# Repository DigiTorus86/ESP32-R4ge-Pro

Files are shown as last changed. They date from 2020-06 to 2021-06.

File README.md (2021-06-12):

# ESP32-R4ge-Pro
<p>
Software and resources for the ESP32 R4ge Pro custom badge. See documents folder for schematic.  
</p>

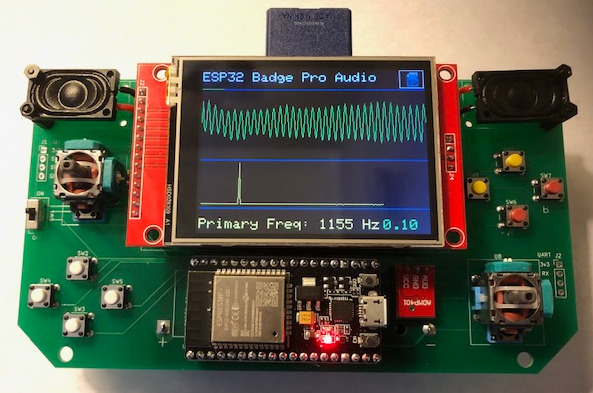
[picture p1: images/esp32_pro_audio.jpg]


<h3>Key Components/Requirements</h3>
<p>
- <a href="https://www.pcbway.com/project/shareproject/ESP32_R4ge_Pro.html">Custom PCB</a><br>
- ESP32 DevKitC w/38 pins (other ESP32 boards can be used with minimal PIN changes)<br>
- ILI9341 320x240 TFT with touch and SD card slot<br>
- 2 Analog joysticks<br>
- PCM5102a I2S DAC w/headphone jack<br>
- PAM8403 amplifier and 8 Ohm/1W speakers and/or powered external speakers w/3.5mm jack<br>
- Microphone (i.e. ADMP401)<br>
- Some sketches have additional hardware requirements (components attached to I2C or Serial pins, or SD card)<br>
- See BOM file in the documents folder for full list of components.<br>
- STL file for printing a simple case also included in the documents folder.<br>
</p>
<h3>App Descriptions</h3>
<p>
- Audio:   Allows for WAV recording, play back, serialization, and frequency analysis.  Requires SD card for some functions.<br>
- BLE Controller:   Allows you to use the joysticks and buttons of the ESP32 R4ge Pro to control another ESP32/Bluetooth device operating in the central role, such as a robot tank.<br> 
- BLE Tank Commander:  Receives BLE control signals from the Controller sketch and feeds them to an H-bridge control board for driving a robot tank or other motorized chassis.  Runs on a generic ESP32 board.<br>   
- Drummer: A 4-channel sequencer using percussion samples.<br>
- Gravitack:  Classic space shooter. (Port from original ESP32 Conference Badge) <br>
- Prong:   A simple pong-type game for 1 or 2 players.<br>
- Synth:   A graphical 4-operator/4-voice FM synth, playable via on-screen keyboard + stylus, 8 step sequencer, or MIDI input on the RX2 pin. 
- Test1:   Used to verify the operation of the board components and do any calibration (microphone/joysticks).<br> 
- Time and Weather:  Clock and weather station. (Port from original ESP32 Conference Badge)<br>
- Tombstone:  Port of the classic TI game.<br>    
- Web Radio:  Internet radio station selector and player.<br>
</p>
<p>
Check for additional info on my blog at https://twobittinker.com<br> 
</p>

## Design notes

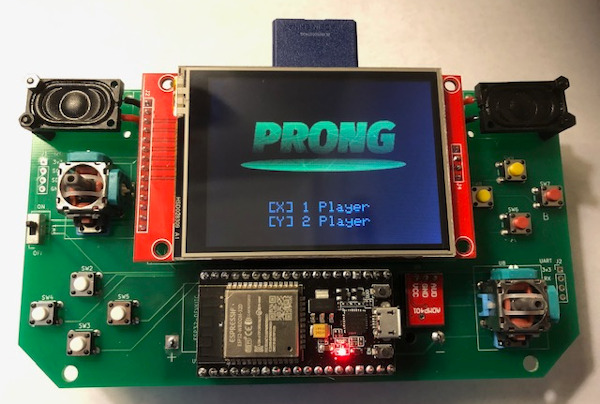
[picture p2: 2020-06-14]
images/esp32_prong.jpg

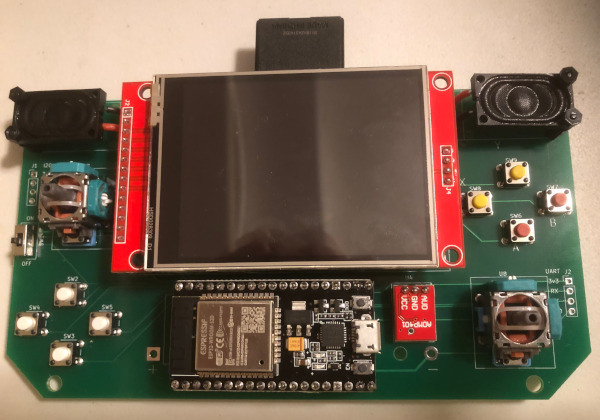
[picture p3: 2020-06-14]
images/ESP32_R4ge_Pro.jpg

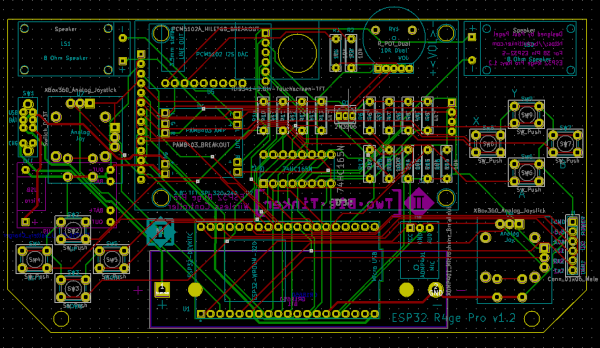
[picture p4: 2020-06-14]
images/ESP32-R4ge-Pro-layoutsm.png

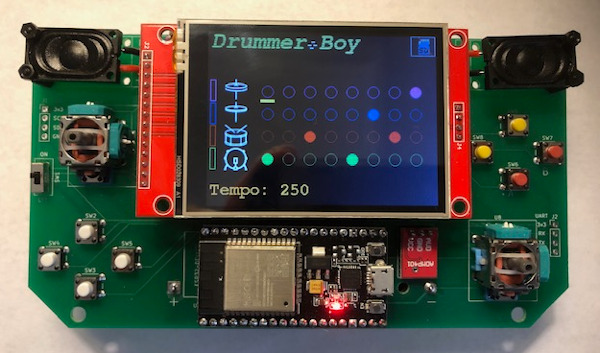
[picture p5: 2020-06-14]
images/esp32_drummer_boy.jpg

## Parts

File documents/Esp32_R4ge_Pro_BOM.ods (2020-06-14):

Component | Description | References | Value | Footprint | Quantity Per PCB | Datasheet | Order URL | Price EA | Total Price
1 | CR18650 Li-Ion rechargeable battery | BT1 | CR18650 | BatteryHolder_MPD_BH-18650-PC2 | 1 | ~ | https://www.amazon.com/gp/product/B07D1FRL54 | 1.25 | 1.25
2 | Generic 2.54mm male break-away connector, single row, 01x06 | J1 | Conn_01x06_Male | PinHeader_1x06_P2.54mm_Vertical | 1 | ~ | https://www.amazon.com/MCIGICM-Header-2-45mm-Arduino-Connector/dp/B07PKKY8BX | 0.5 | 0.5
3 | 8 Ohm 1W Speaker | LS1 LS2 | Speaker | Speaker_Visaton_K14.25_8_ohm | 2 | https://www.mouser.com/datasheet/2/700/k14_25_8-1285071.pdf | https://www.mouser.com/ProductDetail/243-K14.25-8OHM | 4 | 8
4 | -0.2A Ic, -40V Vce, Small Signal PNP Transistor, TO-92 | Q1 | 2N3906 | TO-92_Inline | 1 | https://www.fairchildsemi.com/datasheets/2N/2N3906.pdf | https://www.amazon.com/McIgIcM-Transistor-Bipolar-Transistors-Through/dp/B06XR8399W | 0.03 | 0.03
5 | Resistor | R18 | 100R | R_Axial_DIN0207_L6.3mm_D2.5mm_P7.62mm_Horizontal | 1 | ~ | https://www.amazon.com/EDGELEC-Resistor-Tolerance-Multiple-Resistance/dp/B07QKDSCSM | 0.05 | 0.05
6 | Resistor | R1 R2 R14 R15 R16 | 10K | R_Axial_DIN0207_L6.3mm_D2.5mm_P7.62mm_Horizontal | 5 | ~ | https://www.amazon.com/EDGELEC-Resistor-Tolerance-Resistance-Optional/dp/B07HDGX5LM | 0.05 | 0.25
7 | Resistor | R17 | 1K | R_Axial_DIN0207_L6.3mm_D2.5mm_P7.62mm_Horizontal | 1 | ~ | https://www.amazon.com/EDGELEC-Resistor-Tolerance-Resistance-Optional/dp/B07HDDWFDD | 0.05 | 0.05
8 | Resistor | R6 R7 R8 R9 R10 R11 R12 R13 | 4K7 | R_Axial_DIN0207_L6.3mm_D2.5mm_P7.62mm_Horizontal | 8 | ~ | https://www.amazon.com/EDGELEC-Resistor-Tolerance-Resistance-Optional/dp/B07HDFHPP3 | 0.05 | 0.4
9 | 10k dual channel potentiometer | RV1 | R_POT_Dual | Potentiometer_10K_Dual_Uxcell | 1 | ~ | https://www.amazon.com/gp/product/B00O9Y6Z70 | 1 | 1
10 | Push button switch, generic, two pins | SW2 SW3 SW4 SW5 SW6 SW7 SW8 SW9 | SW_Push | SW_PUSH_6mm | 8 | ~ | https://www.amazon.com/gp/product/B07C7211PJ | 0.06 | 0.48
11 | Dual Pole 3 Position power switch | SW1 | Switch_DP3T | Switch_DP3T_CK_OS203011MS1QP1 | 1 |  | https://www.mouser.com/ProductDetail/611-OS203011MV9QN1 | 0.5 | 0.5
12 | 74HC165N Shift Register, DIP-16 | U3 | 74HC165N | DIP254P762X420-16 | 1 | 380635 | https://www.amazon.com/Brands-74HC165-Semiconductors-Parallel-Register/dp/B06WRRLPSW | 0.8 | 0.8
13 | ADMP401 MEMS microphone breakout | U4 | ADMP401_Microphone_Breakout | ADMP401_Microphone_Breakout | 1 |  | https://www.amazon.com/ADMP401-Microphone-Breakout-Universal-1-3cm1cm/dp/B07VJXP2NN | 4.3 | 4.3
14 | ESP32 WROOM-32D DevkitC/nodeMCU-S w/38 pins | U1 | ESP32-DEVKITC | MODULE_ESP32-DEVKITC | 1 | None | https://www.amazon.com/HiLetgo-ESP-WROOM-32-Development-Microcontroller-Integrated/dp/B0718T232Z | 10.99 | 10.99
15 | 2.8” SPI Touchscreen TFT w/SD card, ILI9341 | U2 | ILI9341-2.8in-Touchscreen-TFT | ILI9341_2.8_TFT_TOUCH_SD_SPI | 1 | http://pan.baidu.com/s/11Y990 | https://www.amazon.com/gp/product/B073R7BH1B | 13.99 | 13.99
16 | PAM8403 stereo amplifier breakout | U6 | PAM8403_BREAKOUT | PAM8403_Breakout_HW104 | 1 |  | https://www.amazon.com/gp/product/B00LODGV64 | 1.08 | 1.08
17 | PCM5102 I2S stereo DAC breakout | U5 | PCM5102A_HILETGO_BREAKOUT | PCM5102A_Hiletgo_Breakout | 1 |  | https://www.amazon.com/HiLetgo-Lossless-Digital-Converter-Raspberry/dp/B07Q9K5MT8 | 8 | 8
18 | TP4056 5v Li-Ion battery charger w/diode protection | U9 | TP4056_5V_Li_Battery_Charger | TP4056_Li_Battery_Charger_Breakout | 1 |  | https://www.amazon.com/gp/product/B071RG4YWM | 1 | 1
19 | XBox360 analog joystick | U7 U8 | XBox360_Analog_Joystick | XBox360_Analog_Joystick | 2 |  | https://www.amazon.com/Replacement-Analog-Controller-Joystick-Playstation/dp/B07SW7SRLH | 1.5 | 3
20 | Generic 2.54mm female header connectors | U1, U2 | for ESP32 and TFT |  | 2 |  | https://www.amazon.com/Haobase-2-54mm-Straight-Single-Headers/dp/B01DLX6RSQ | 0.56 | 1.12
 | 16pin IC socket | U3 | for 74HC165N |  | 1 |  | https://www.amazon.com/Uxcell-a11090300ux0244-2-54mm-Socket-Adaptors/dp/B0079SM1LW | 0.35 | 0.35
 |  |  |  |  |  |  |  | TOTAL | 57.14
Component Groups: | 19
Component Count: | 39
Fitted Components: | 39
Number of PCBs: | 1
Total components: | 39
Schematic Version: | 3
Schematic Date: | 2020-04-05
PCB Variant: | [u'default']
BoM Date: | Wed 08 Apr 2020 05:32:06 PM EDT
Schematic Source: | /home/digitorus/KiCad/ESP32_R4ge_Pro/Esp32Badge-v1/Esp32Badge-v1.sch
KiCad Version: | Eeschema 5.1.5-52549c5~86~ubuntu19.10.1

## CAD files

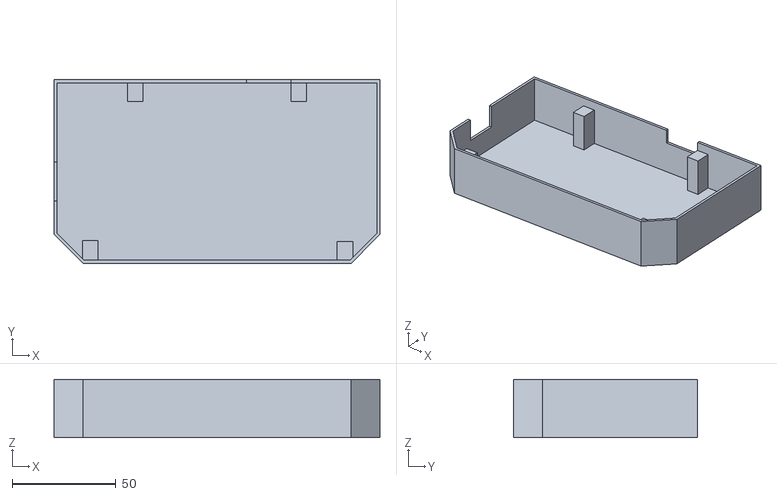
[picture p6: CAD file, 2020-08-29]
documents/Rage_Pro_Case3.stl
156.8 x 88.4 x 28.0

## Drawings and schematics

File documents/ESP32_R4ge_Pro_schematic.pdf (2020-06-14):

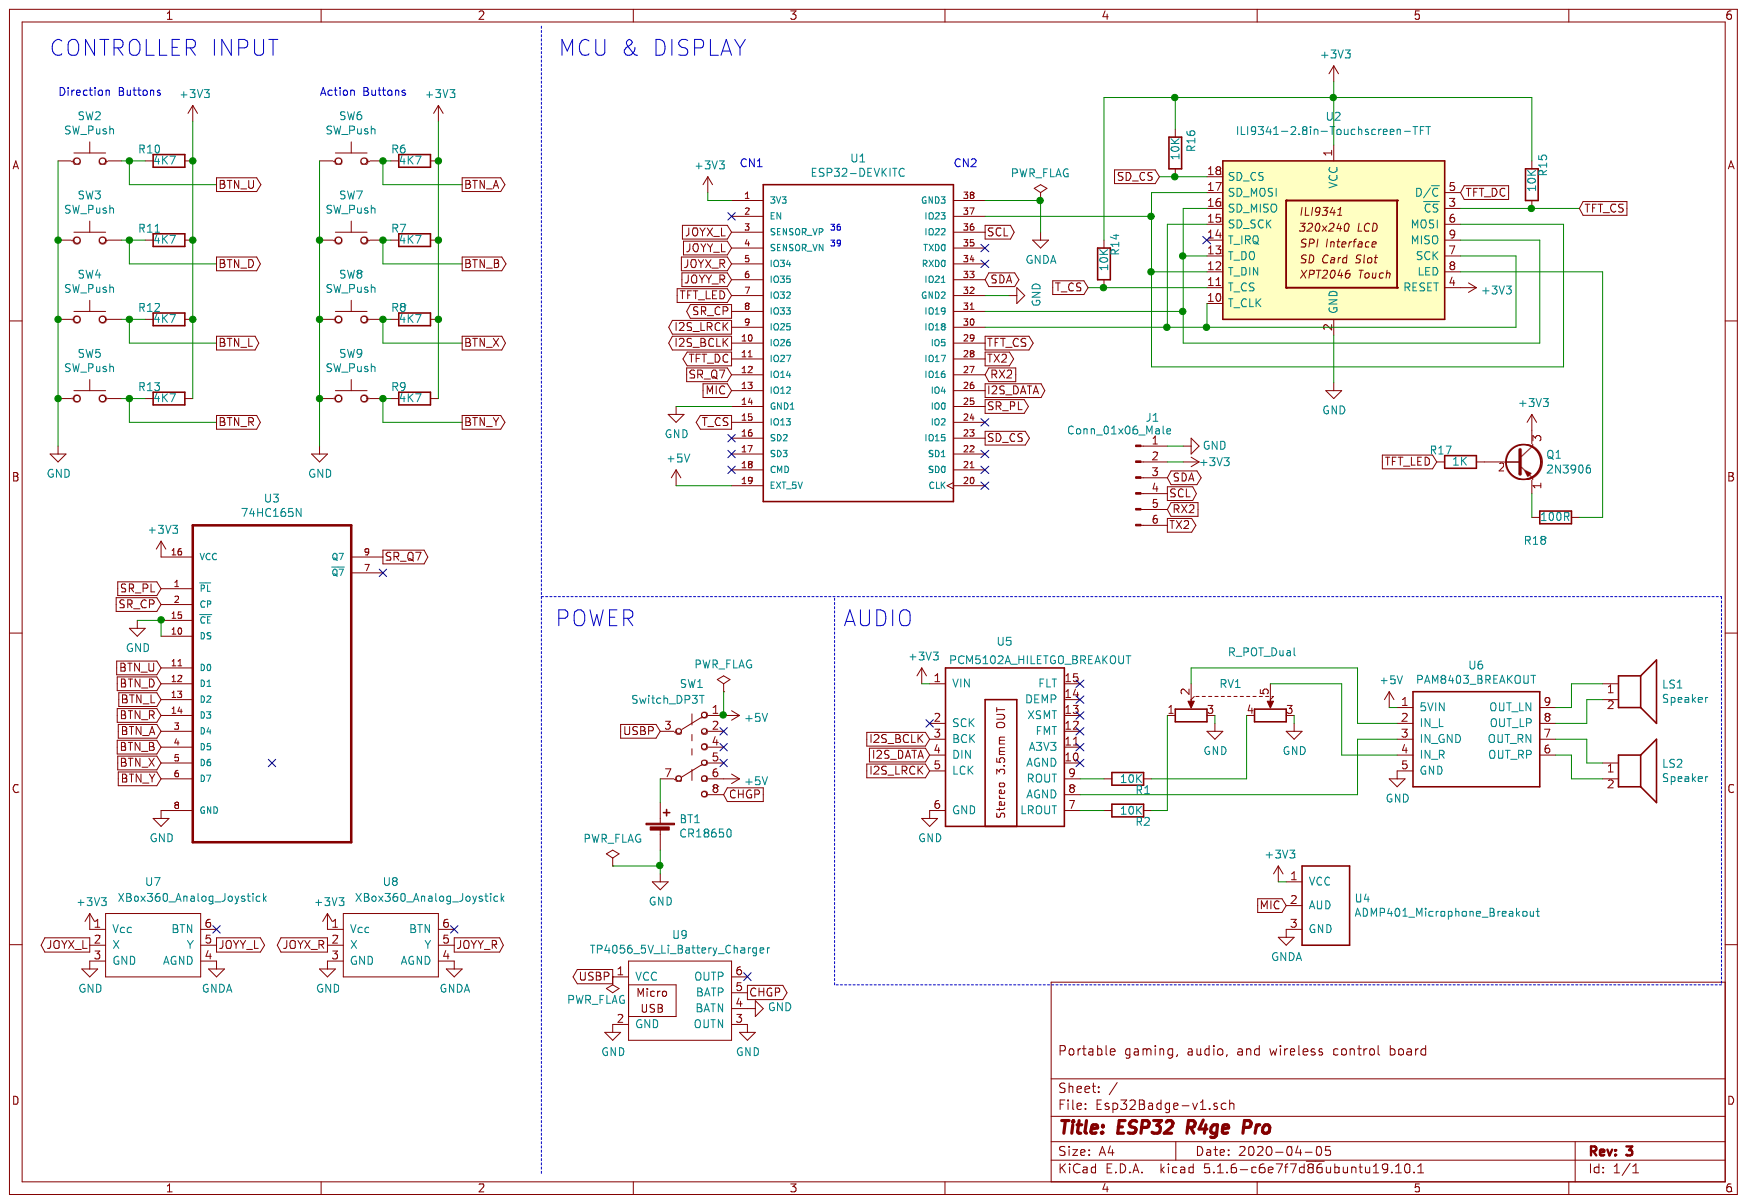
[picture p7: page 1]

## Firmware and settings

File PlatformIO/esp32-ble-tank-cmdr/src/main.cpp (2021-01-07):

/***************************************************
 ESP32 BLE Tank Commander (central role)
  
 Sketch for operating a remote control tank in a BLE central role.
 This sketch runs on the ESP32 attached to the tank chassis 
 via a dual H-bridge control board such as the  L298N DC Stepper Motor Driver Module. 
 See the esp32-r4ge-ble-controller sketch for the remote control peripheral unit.

Requires:
- ESP32 (i.e. DevKitC or other similar board)
- Dual motorized tank chassis (though can be adapted to single motors)
- H-Bridge Driver board
- An ESP32 R4ge Pro running the BLE Controller sketch

Copyright (c) 2021 Paul Pagel
This is free software; see the license.txt file for more information.
There is no warranty; not even for merchantability or fitness for a particular purpose.
*****************************************************/

#include <Arduino.h>
#include <BLEDevice.h>
#include <BLEUtils.h>
#include <BLEServer.h>
#include <BLE2902.h>

#define BLE_DEVICE_ID   "Cmdr1"  // Adjust as desired, but keep short

// UPDATE PERIPHERAL ADDRESS PRIOR TO RUNNING THIS SKETCH!!
// Specific MAC address of the peripheral controller device you're looking for.
// Should be in ff:ff:ff:ff:ff:ff format (6 bytes plus colon separators)
// This value is displayed at the bottom of the screen by the 
// esp32-r4ge-ble-controller sketch.
String esp32_peripheral_address = "24:6f:28:b6:19:22"; 

// UUIDs for the BLE service and characteristic - must match the central
// Generate new GUIDs if you modify the data packet size/format
#define SERVICE_UUID        "788fce9d-5ba6-4e8f-9e98-5965b20ab856"
#define CHARACTERISTIC_UUID "e2cdb570-6340-4aa2-9ac3-ab32cfa371f3"

#define MOTOR_L_POS  19  // L289N IN1 = tank left tread  Motor A +
#define MOTOR_L_NEG  18  // L289N IN2 = tank left tread  Motor A -
#define MOTOR_L_EN    5  // L289N ENA = tank left tread  Motor Enable (PWM/speed)

#define MOTOR_R_POS  25  // L289N IN3 = tank right tread Motor B +
#define MOTOR_R_NEG  26  // L289N IN4 = tank right tread Motor B -  
#define MOTOR_R_EN   23  // L289N ENA = tank right tread Motor Enable (PWM/speed)

#define CAM_ELEV8     2  // camera elevation servo (PWM)r
#define PAIR_LED      0  

uint8_t channel_left = 0;
uint8_t channel_right = 1;
uint8_t channel_elev8 = 2;
uint8_t duty_left = 128;
uint8_t duty_right = 128;
uint8_t duty_elev8 = 8;

static BLERemoteCharacteristic* 
                    remote_characteristic;
BLEScan*            ble_scan; //BLE scanning device 
BLEScanResults      found_devices;
static BLEAddress*  server_ble_address;
String              server_ble_address_str;
bool                server_paired = false;
bool                client_connected = false;
bool                data_received = false;


#define PACKET_SIZE 4
#define DP_CMND     0
#define DP_LTRK     1
#define DP_RTRK     2
#define DP_ELEV     3

#define DP_CMND_LTRKFWD   1  
#define DP_CMND_LTRKBWD   2
#define DP_CMND_RTRKFWD   4
#define DP_CMND_RTRKBWD   8
#define DP_CMND_PICTURE  16

uint8_t data_packet[] = 
{
   0x00,  // command flags
   0x00,  // left tread (0 = fwd, 127 = stop, 255 = bkwd 
   0x00,  // right tread
   0x00,  // elevation position
};

/*
 * Callback used when scanning for BLE peripheral/server devices
 */
class MyAdvertisedDeviceCallbacks: public BLEAdvertisedDeviceCallbacks
{
    void onResult(BLEAdvertisedDevice advertisedDevice) 
    {
      Serial.printf("Scan Result: %s \n", advertisedDevice.toString().c_str());
      BLEAddress *foundAddress = new BLEAddress(advertisedDevice.getAddress());
      String bleAddr = foundAddress->toString().c_str();

      Serial.println(bleAddr);

      if (bleAddr == esp32_peripheral_address)
      {
        Serial.printf("Found specified peripheral\n");
        server_ble_address = new BLEAddress(advertisedDevice.getAddress());
        server_ble_address_str = server_ble_address->toString().c_str();
      }
    }
};

/* 
 * Callbacks used with BLE control device 
 */
class MyClientCallbacks: public BLEClientCallbacks
{
  void onConnect(BLEClient *pClient)
  {
    client_connected = true;
  }
  
  void onDisconnect(BLEClient *pClient)
  {
    client_connected = false;
    server_paired = false;
  }
};

/*
 * Called every time we get BLE Control data from the peripheral server device
 */
static void notifyCallback(BLERemoteCharacteristic* pBLERemoteCharacteristic, uint8_t* pData, size_t length, bool isNotify) 
{
    Serial.print("Notify callback for characteristic ");
    Serial.print(pBLERemoteCharacteristic->getUUID().toString().c_str());
    Serial.print(" of data length ");
    Serial.println(length);
    Serial.print("data: ");
    Serial.println((char*)pData);
    
    if (length != PACKET_SIZE)
      return;
    
    for (int i = 0; i < length; i++)
    {
        data_packet[i] = pData[i];
        Serial.println(data_packet[i]);
    }
    data_received = true;
}

/*
 * Connect to a peripheral BLE control server address that we found during the scan
 */
bool connectToServer(BLEAddress pAddress){
    
    BLEClient*  pClient  = BLEDevice::createClient();
    pClient->setClientCallbacks(new MyClientCallbacks()); 
    Serial.println(" - Created client");

    // Connect to the BLE Server.
    pClient->connect(pAddress);
    Serial.println(" - Connected to ESP32 Peripheral");

    // Obtain a reference to the service we are after in the remote BLE server.
    BLERemoteService* pRemoteService = pClient->getService(SERVICE_UUID);
    if (pRemoteService == nullptr)
    {
      Serial.println(" - Unable to find control data service.");
      return false;
    }
     Serial.println(" - data control service found.");
    
    // Obtain a reference to the characteristic in the service of the remote BLE server.
    remote_characteristic = pRemoteService->getCharacteristic(CHARACTERISTIC_UUID);
    if (remote_characteristic == nullptr)
    {
      Serial.println(" - Unable to find Control characteristic.");
      return false;
    }
    Serial.println(" - Control characteristic found.");
    
    if(remote_characteristic->canNotify())
      remote_characteristic->registerForNotify(notifyCallback);
    
    return true;
}

/*
 * Process the received control data and map it to internal state variables
 */
void processDataPacket()
{
  // TODO: data_packet[] values to control
  // 0=cmd, 1=left track, 2=right track, 3=elevate

  duty_left = data_packet[DP_LTRK] << 1;
  duty_right = data_packet[DP_RTRK] << 1;
  ledcWrite(channel_left, duty_left);  
  ledcWrite(channel_right, duty_right);   

  // Control left track direction
  if (data_packet[DP_CMND] & DP_CMND_LTRKFWD)
  {
    digitalWrite(MOTOR_L_POS, LOW);
    digitalWrite(MOTOR_L_NEG, HIGH); 
  }
  else if (data_packet[DP_CMND] & DP_CMND_LTRKBWD)
  {
    digitalWrite(MOTOR_L_POS, HIGH);
    digitalWrite(MOTOR_L_NEG, LOW); 
  }
  else
  {
    digitalWrite(MOTOR_L_POS, LOW);
    digitalWrite(MOTOR_L_NEG, LOW); 
  }

  // Control right track direction
  if (data_packet[DP_CMND] & DP_CMND_RTRKFWD)
  {
    digitalWrite(MOTOR_R_POS, LOW);
    digitalWrite(MOTOR_R_NEG, HIGH); 
  }
  else if (data_packet[DP_CMND] & DP_CMND_RTRKBWD)
  {
    digitalWrite(MOTOR_R_POS, HIGH);
    digitalWrite(MOTOR_R_NEG, LOW); 
  }
  else
  {
    digitalWrite(MOTOR_R_POS, LOW);
    digitalWrite(MOTOR_R_NEG, LOW); 
  }

  // TODO: handle other commands here
}

/*
 * Kick off the process of finding and paring with the Control server.
 * Returns true if successfully found and paired.
 */
bool pairBlePeripheral()
{
  server_ble_address_str = "";
  digitalWrite(PAIR_LED, LOW); 
  
  ble_scan = BLEDevice::getScan(); //create new scan
  ble_scan->setAdvertisedDeviceCallbacks(new MyAdvertisedDeviceCallbacks()); //Call the class that is defined above
  ble_scan->setActiveScan(true); //active scan uses more power, but get results faster
  
  found_devices = ble_scan->start(3); //Scan for 3 seconds to find the Control Gauntlet

  if (found_devices.getCount() >= 1 && !server_paired)
  {
    if (server_ble_address_str.length() > 0)
    {
      if (connectToServer(*server_ble_address))
      {
        server_paired = true;
        digitalWrite(PAIR_LED, HIGH);
        Serial.print("Control server paired: ");
        Serial.println(server_ble_address_str.c_str());
        
        return true; // found peripheral controller
      }
    }
  }
  return false;
}
 
void setup() 
{
  Serial.begin(115200);
  Serial.println("ESP32 Tank Commander"); 
  delay(100);
  
  pinMode(MOTOR_L_POS, OUTPUT);
  pinMode(MOTOR_L_NEG, OUTPUT);
  pinMode(MOTOR_L_EN, OUTPUT);
  
  pinMode(MOTOR_R_POS, OUTPUT);
  pinMode(MOTOR_R_NEG, OUTPUT);
  pinMode(MOTOR_R_EN, OUTPUT);

  pinMode(CAM_ELEV8, OUTPUT);
  pinMode(PAIR_LED, OUTPUT);

  ledcSetup(channel_left, 20000, 8);  // 20 kHz max, 8 bit resolution
  ledcAttachPin(MOTOR_L_EN, channel_left);
  ledcWrite(channel_left, duty_left);  

  ledcSetup(channel_right, 20000, 8);  // 20 kHz max, 8 bit resolution
  ledcAttachPin(MOTOR_R_EN, channel_right);
  ledcWrite(channel_right, duty_right);   

  ledcSetup(channel_elev8, 50, 8);  // 50 Hz max, 8 bit resolution
  ledcAttachPin(CAM_ELEV8, channel_elev8);
  ledcWrite(channel_elev8, duty_elev8);   

  if (esp32_peripheral_address.length() != 17)
  {
    Serial.println("Please configure a valid ESP32 peripheral address!");
    Serial.println("Valid fmt: 01:02:03:f1:f2:f3");
    while(true);
  }

  BLEDevice::init("");
  
  while (!pairBlePeripheral())
  {
    digitalWrite(PAIR_LED, HIGH);
    delay(100);
    digitalWrite(PAIR_LED, LOW);
    delay(3000);
  }
}

void loop() 
{
  if (!client_connected)
  {
    digitalWrite(PAIR_LED, LOW);
    while (!pairBlePeripheral())
    {
      digitalWrite(PAIR_LED, HIGH);
      delay(100);
      digitalWrite(PAIR_LED, LOW);
      delay(3000);
    }
  }

  
  if (data_received)
  {
    //digitalWrite(DATA_LED_PIN, HIGH);
    processDataPacket();
  
    data_received = false;
    delay(10);
    //digitalWrite(DATA_LED_PIN, LOW);
  }
}

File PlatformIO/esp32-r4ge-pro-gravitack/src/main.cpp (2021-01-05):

/***************************************************
ESP32 Badge - Gravitack game
An homage to the classic arcade console
by Paul Pagel

Requires:
 - ESP32 R4ge Pro
 - ESP8266Audio library:  https://github.com/earlephilhower/ESP8266Audio 

Copyright (c) 2021 Paul Pagel
This is free software; see the license.txt file for more information.
There is no warranty; not even for merchantability or fitness for a particular purpose.
*****************************************************/

#include <Arduino.h>
#include <SD.h>
#include "esp32_r4ge_pro.h"
#include <WiFi.h>
#include "AudioFileSourcePROGMEM.h"
#include "AudioGeneratorWAV.h"
#include "AudioOutputI2S.h"

#include "Levels.h"
#include "Bitmaps.h"
#include "fire_wav.h"
#include "refuel_wav.h"
#include "explosion_wav.h"
#include "warp_wav.h"
#include "tick_wav.h"

#define SHIP_SIZE    8
#define THRUST_SIZE  3 
#define SHOT_SPEED   8
#define MAX_SHOTS    4
#define MAX_GROUND  32
#define MAX_FUEL     8
#define MAX_TURRET   8
#define MAX_LIVES    6

#define PLAYER_FUEL_X 30
#define GAME_TOP   20 
#define FUEL_WD     8
#define FUEL_HT    16
#define INVALID_ITEM 999

enum game_state_type {
  STATE_TITLE,
  STATE_RULES,
  STATE_PLAYING,
  STATE_PAUSED,
  STATE_GAME_OVER
};

enum direction_type {
  DIR_UP = 1,
  DIR_DOWN = 2,
  DIR_LEFT = 3,
  DIR_RIGHT = 4
};

enum game_state_type game_state;

// constants used to speed up trig calculations
const double PId2  = PI / 2;
const double PId15 = PI / 1.5;
const double PIx15 = PI * 1.5;
const double PIx075 = PI * 0.75;

bool btn_was_pressed[8], btn_pressed[8], btn_released[8];
int16_t joy_x_left, joy_y_left, joy_x_right, joy_y_right; 

static int    player_start_x, player_start_y;
static double player_ctr_x = SCREEN_WD / 2;
static double player_ctr_y = SCREEN_HT / 4;
static double player_rotation = PIx15;
static double player_speed_x;
static double player_speed_y;
static double player_fuel;
static int    player_lives;
static long   player_score;
static long   next_ship = 10000;
static double gravity = 0.02;
static int    level;
static int    level_delay = 10;

int ship_x[9];
int ship_y[9];
int shot_x[MAX_SHOTS];
int shot_y[MAX_SHOTS];
int shot_range[MAX_SHOTS];
double shot_speed_x[MAX_SHOTS];
double shot_speed_y[MAX_SHOTS];
int player_shot_range; // # of game loops new shots can exist

int ground_x[MAX_GROUND];
int ground_y[MAX_GROUND];
int ground_size = 0;  // # of ground line segments in the current level

int  fuel_x[MAX_FUEL];
int  fuel_y[MAX_FUEL];
bool fuel_active[MAX_FUEL];
int  fuel_count;    // # starting fuel packs in level
int  fuel_remaining;  // # remaining fuel packs in level

int  turret_x[MAX_TURRET];
int  turret_y[MAX_TURRET];
int  turret_dir[MAX_TURRET];
bool turret_active[MAX_TURRET];
int  turret_shot_x[MAX_TURRET];
int  turret_shot_y[MAX_TURRET];
int  turret_shot_range[MAX_TURRET];
double turret_shot_speed_x[MAX_TURRET];
double turret_shot_speed_y[MAX_TURRET];
int  turret_range;    // # of game loops new turret shots can exist
int  turret_count;    // # starting turrets in level
int  turret_remaining;  // # remaining turrets in level

int turret_offset_x[4] = { 10, 10,-10, 20};
int turret_offset_y[4] = {-10, 10, 10, 10};

// Sound FX
AudioGeneratorWAV *wav;
AudioFileSourcePROGMEM *fire_file;
AudioFileSourcePROGMEM *explosion_file;
AudioFileSourcePROGMEM *refuel_file;
AudioFileSourcePROGMEM *tick_file;
AudioFileSourcePROGMEM *warp_file;
AudioOutputI2S *audio_out;

Adafruit_ILI9341 tft = Adafruit_ILI9341(TFT_CS, TFT_DC, TFT_RST);

void drawTitleScreen();
void drawRulesScreen();
void startGame(int startLevel);
void drawPaused();
void erasePaused();
void drawGameOver();
void wipeGameArea();
void playShotSound();
void playExplosionSound();
void playRefuelSound();
void playTickSound();
void playWarpSound();
void drawExplosion(int x, int y, int maxRadius);
void initShots();
void loadLevelData(const int levelData[]);
void loadLevel(int lvl);
void drawGround();
void drawHeader();
void drawPlayerFuel();
void changePlayerFuel(int changeAmt);
void changePlayerScore(int changeAmt);
void drawPlayerLives();
void drawFuelPacks();
void drawFuelPack(int x, int y);
void eraseFuelPack(int x, int y);
void drawTurrets(int shotRate);
void drawTurret(int x, int y, int direction);
void eraseTurret(int x, int y, int direction);
void drawShip(int ctrX, int ctrY, double rotation, bool thrust);
void eraseShip();
void createPlayerShot(int x, int y, double rotation);
void movePlayerShots();
void movePlayerShot(int idx);
void createTurretShot(int x, int y);
bool moveTurretShots();
bool moveTurretShot(int idx);
bool hitsPlayer(int x, int y, double tolerance);
int  checkFuelHit(int x, int y, double tolerance);
bool hitsFuel(int idx, int x, int y, double tolerance);
int  checkTurretHit(int x, int y, double tolerance);
bool hitsTurret(int idx, int x, int y, double tolerance);
bool hitsGround(int x, int y, double tolerance);
bool hitsLine(int x, int y, int lineX1, int lineY1, int lineX2, int lineY2, double tolerance);
void startPlayer();
void killPlayer();
void advanceLevel();
void checkButtonPresses();
void checkJoysticks();
void checkAudio();
void delayAudio(long ms);
void handleTitle();
void handleRules();
void handlePlaying();
void handlePaused();
void handleGameOver();


/*
 *  Initialize hardware, peripherals, and libraries
 */
void setup() 
{
  Serial.begin(9600);
  Serial.println("ESP32 R4ge Pro - Gravitack"); 
  delay(100);

  Serial.print("Setting up pins..."); 
  pinMode(ESP_LED, OUTPUT);  // built-in blue LED on NodeMCU

  // Set up shift register pins
  pinMode(SR_PL, OUTPUT);
  pinMode(SR_CP, OUTPUT);   
  pinMode(SR_Q7, INPUT);

  // Set up the SPI CS output pins
  pinMode(TFT_CS, OUTPUT);
  pinMode(TCH_CS, OUTPUT);
  pinMode(SD_CS, OUTPUT);

  pinMode(TFT_LED, OUTPUT);
  digitalWrite(TFT_LED, LOW); // full brightness
  
  // Set up the joysticks
  pinMode(JOYX_L, INPUT);
  pinMode(JOYY_L, INPUT);
  pinMode(JOYX_R, INPUT);
  pinMode(JOYY_R, INPUT);

  Serial.println("done"); 
  delay(100);
  
  // Set up the TFT and touch screen
  Serial.print("Setting display..."); 
  tft.begin();
  tft.setRotation(SCREEN_ROT);
  Serial.println("done"); 

  Serial.print("Setting audio..."); 

  audioLogger = &Serial;
  explosion_file = new AudioFileSourcePROGMEM(explosion_wav, sizeof(explosion_wav));
  fire_file = new AudioFileSourcePROGMEM(fire_wav, sizeof(fire_wav));
  refuel_file = new AudioFileSourcePROGMEM(refuel_wav, sizeof(refuel_wav));
  tick_file = new AudioFileSourcePROGMEM(tick_wav, sizeof(tick_wav));
  warp_file = new AudioFileSourcePROGMEM(warp_wav, sizeof(warp_wav));
  audio_out = new AudioOutputI2S();
  audio_out->SetPinout(I2S_BCLK, I2S_LRCK, I2S_DOUT);
  wav = new AudioGeneratorWAV();

  Serial.println("done"); 

  drawTitleScreen();
}
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

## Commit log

2020-06-14 initial upload
    [Esp32_R4ge_Pro_BOM.ods]
2020-08-29 Added basic case STL file
    [Rage_Pro_Case3.stl]
2021-06-12 Add Gerbers
    [Esp32Badge-v1-B_Cu.gbr, Esp32Badge-v1-B_Mask.gbr, Esp32Badge-v1-B_Paste.gbr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]
2024-01-12 Fix ESP8266 audio issue
    [main.cpp]
